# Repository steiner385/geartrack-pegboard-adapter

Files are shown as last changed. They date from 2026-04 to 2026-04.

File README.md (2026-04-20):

# GearTrack Pegboard Adapter

A 3D-printable adapter that slides into Gladiator GearTrack/GearWall channels and presents standard 1/4" pegboard holes — so you can reuse your existing pegboard hooks on GearTrack.

## Features

- **Exact GearTrack fit** — bracket profile traced from [CosmicProphet's GearTrack Mounting Brackets](https://www.thingiverse.com/thing:4075984)
- **Self-contained** — single OpenSCAD file, no external dependencies
- **Standard pegboard holes** — 1/4" (6.35mm) holes on 1" (25.4mm) centers
- **Fully parametric** — customize width, height, standoff depth, and more via OpenSCAD or Thingiverse Customizer
- **Hook clearance** — adjustable standoff (default 17mm) behind the plate for hook backs
- **Smart tab distribution** — GearTrack tabs at the edges, evenly distributed, never behind holes

## Pre-generated STLs

| File | Width × Height | Tabs | Description |
|---|---|---|---|
| `Test_Clip` | — | 1 | Print first to verify GearTrack fit |
| `2x2` | 2 × 2 | 1 | Single hook spot |
| `4x3` | 4 × 3 | 1 | Compact tool cluster |
| `4x4` | 4 × 4 | 1 | Square panel |
| `4x6` | 4 × 6 | 1 | Tall narrow panel |
| `4x8` | 4 × 8 | 1 | Very tall panel |
| `6x3` | 6 × 3 | 2 | Wide short panel |
| `6x4` | 6 × 4 | 2 | Wide standard panel |
| `8x3` | 8 × 3 | 2 | Near max bed width (220mm) |
| `8x4` | 8 × 4 | 2 | Largest single print |

## Customizer Parameters

- **Width**: Columns across (even: 2, 4, 6, 8)
- **Height**: Rows tall (1–12)
- **Standoff**: Hook clearance behind plate (12–25mm, default 17)
- **Plate thickness**: 3–8mm (default 5)
- **Hole diameter**: Default 6.35mm (1/4")
- **Hole spacing**: Default 25.4mm (1")
- **Test clip mode**: Print just the GearTrack tab to verify fit

## Print Settings

- **Orientation**: Flat on bed
- **Infill**: 50–80%, rectilinear
- **Perimeters**: 3+
- **Material**: PLA or PETG (PETG recommended for garage use)
- **Supports**: Not required

## Usage

1. Print the **Test Clip** first to verify it slides into your GearTrack
2. If too tight, increase tolerance by scaling the clip 99% in your slicer
3. Choose or customize a pegboard size
4. Print, slide into GearTrack from the end, and hang your hooks

## Files

- `geartrack_pegboard_adapter.scad` — Parametric OpenSCAD source (Thingiverse Customizer compatible)
- `GearTrack_Pegboard_*.stl` — Pre-generated common sizes

## Attribution

GearTrack bracket profile traced from [CosmicProphet's GearTrack Mounting Brackets](https://www.thingiverse.com/thing:4075984), licensed under [CC BY 4.0](https://creativecommons.org/licenses/by/4.0/).

## License

This work is licensed under [CC BY 4.0](https://creativecommons.org/licenses/by/4.0/).

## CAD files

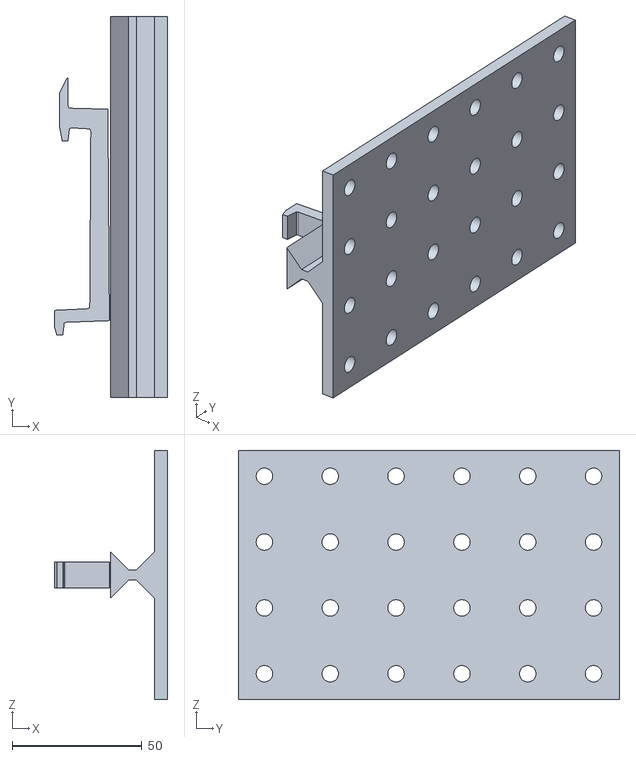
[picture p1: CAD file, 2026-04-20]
GearTrack_Pegboard_4x6.stl
43.6 x 147.0 x 96.2

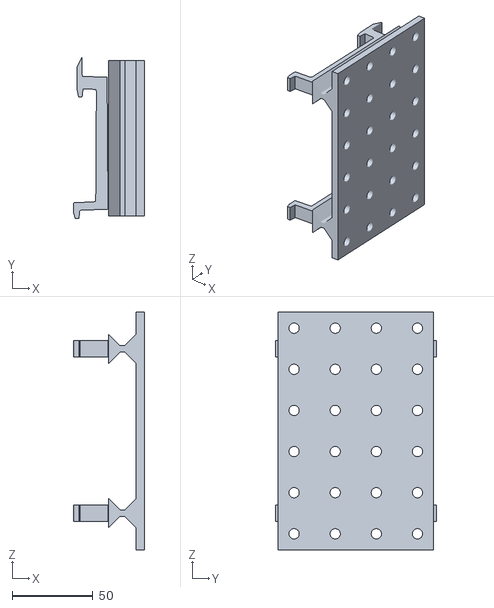
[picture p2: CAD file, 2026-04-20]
GearTrack_Pegboard_6x4.stl
43.6 x 99.2 x 147.0

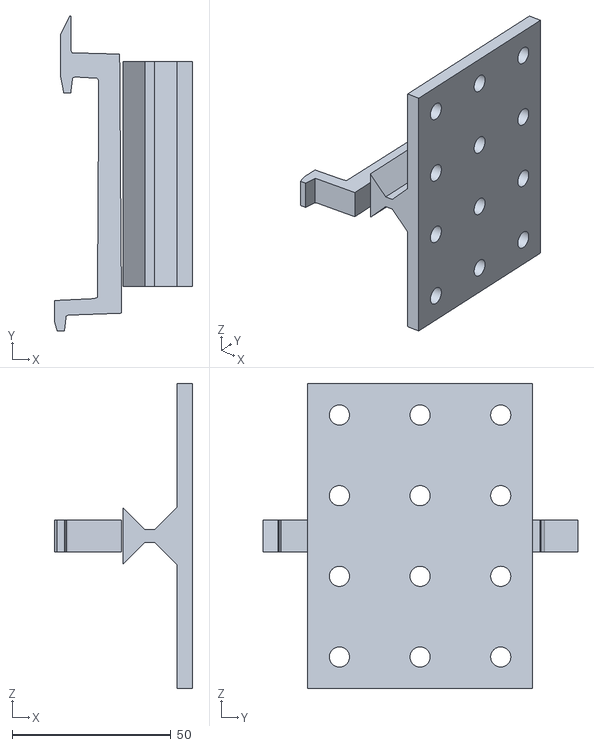
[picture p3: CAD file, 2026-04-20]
GearTrack_Pegboard_4x3.stl
43.6 x 99.2 x 96.2

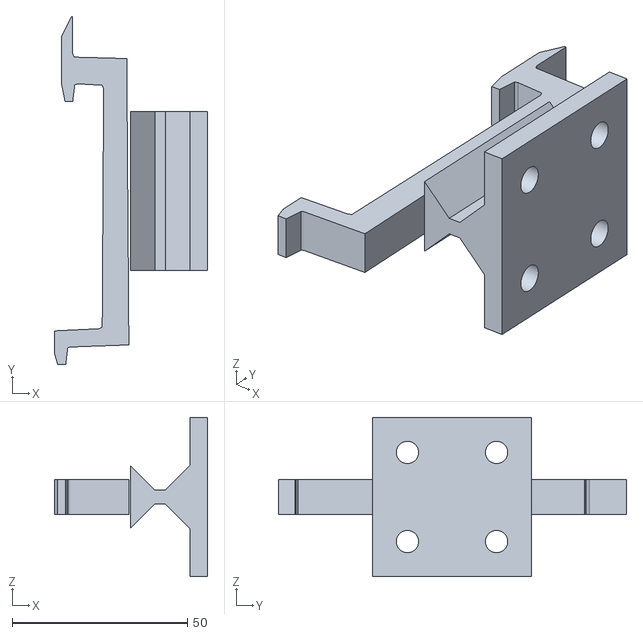
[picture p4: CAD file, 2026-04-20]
GearTrack_Pegboard_2x2.stl
43.6 x 99.2 x 45.4

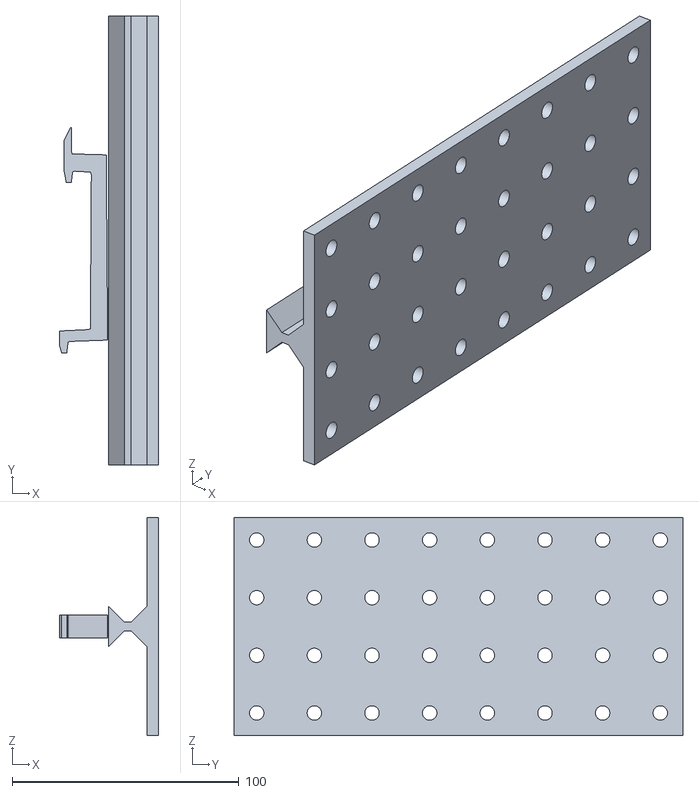
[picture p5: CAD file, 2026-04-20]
GearTrack_Pegboard_4x8.stl
43.6 x 197.8 x 96.2

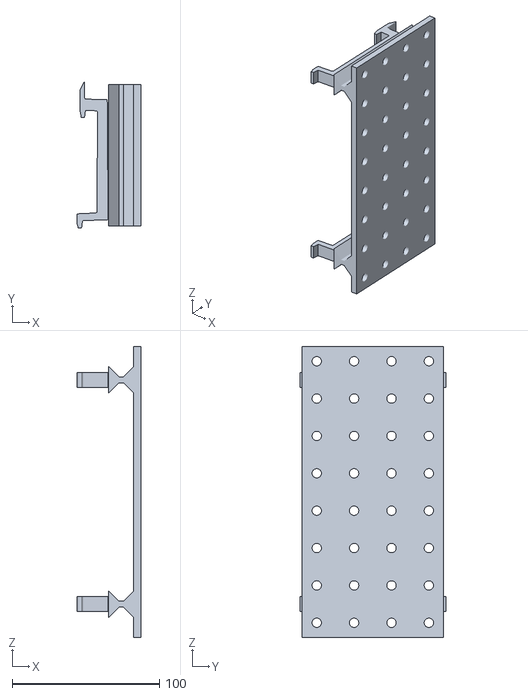
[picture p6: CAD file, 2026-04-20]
GearTrack_Pegboard_8x4.stl
43.6 x 99.2 x 197.8

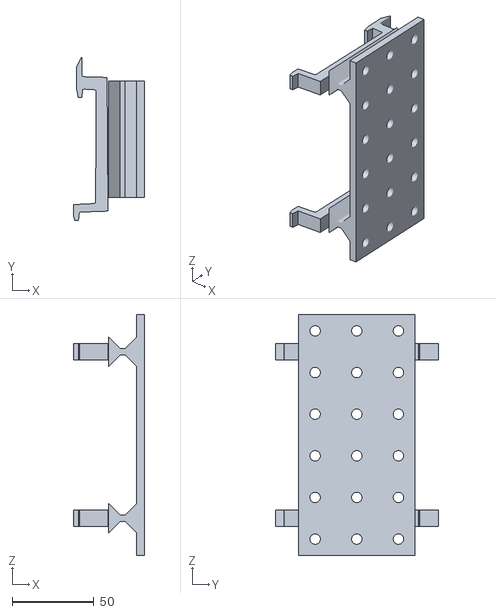
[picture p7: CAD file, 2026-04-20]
GearTrack_Pegboard_6x3.stl
43.6 x 99.2 x 147.0

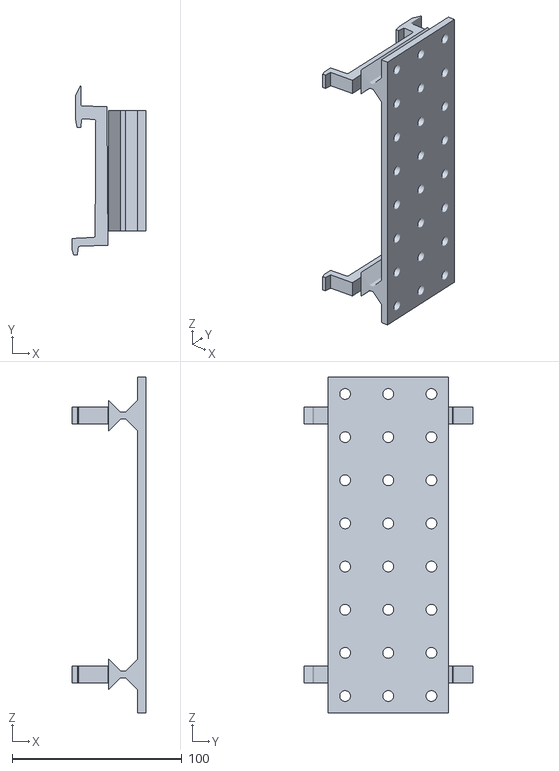
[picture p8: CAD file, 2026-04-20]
GearTrack_Pegboard_8x3.stl
43.6 x 99.2 x 197.8

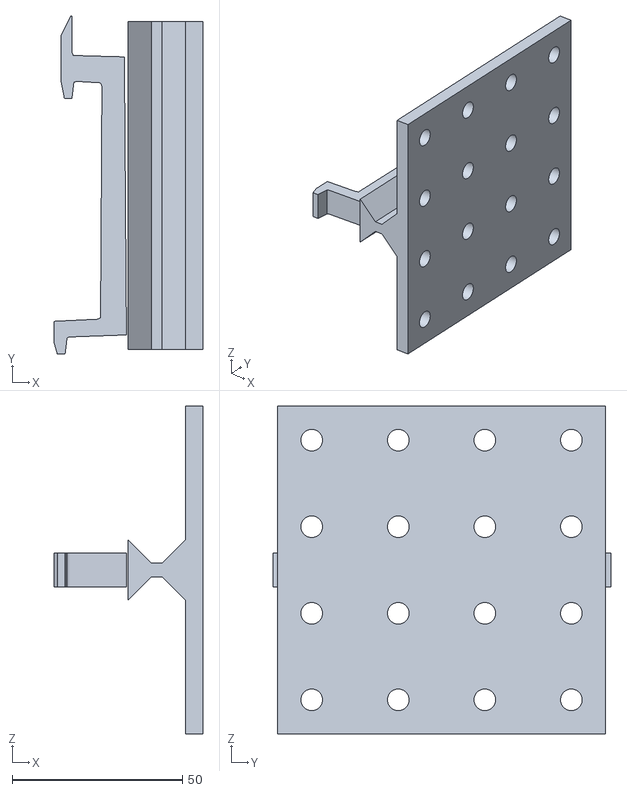
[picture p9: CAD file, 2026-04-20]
GearTrack_Pegboard_4x4.stl
43.6 x 99.2 x 96.2

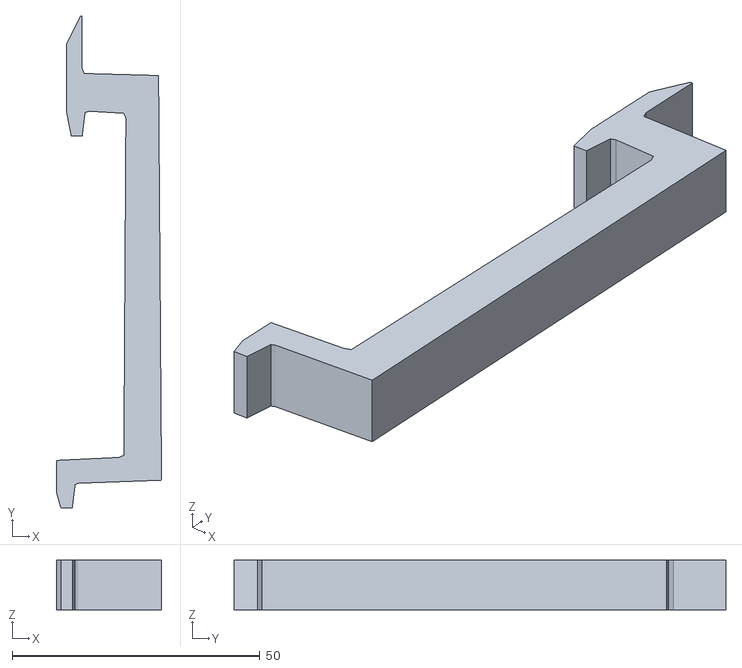
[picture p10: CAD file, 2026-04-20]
GearTrack_Pegboard_Test_Clip.stl
21.2 x 99.2 x 10.0

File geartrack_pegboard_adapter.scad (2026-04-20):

// GearTrack-to-Pegboard Adapter
// Slides into Gladiator GearTrack/GearWall channels and presents
// standard 1/4" pegboard holes for your existing hooks.
//
// Self-contained — no external dependencies.
// Bracket profile derived from CosmicProphet's GearTrack Mounting
// Brackets (Thingiverse thing:4075984), licensed CC BY 4.0.
//
// Print settings:
//   Orientation: flat on bed
//   Infill: 50-80%, rectilinear
//   Perimeters: 3+
//   Material: PLA or PETG (PETG recommended for garage use)
//   Supports: not required

/* [Pegboard] */

// Columns across (horizontal, along the track). Even numbers only.
width = 4; // [2, 4, 6, 8]

// Rows tall (vertical, up the wall)
height = 3; // [1:1:12]

// Hole diameter in mm (standard = 6.35 / 1/4 inch)
hole_dia = 6.35;

// Hole center-to-center spacing in mm (standard = 25.4 / 1 inch)
hole_spacing = 25.4;

/* [Plate] */

// Plate thickness in mm
plate_thick = 5.0; // [3:0.5:8]

// Margin around outermost holes in mm
plate_margin = 10.0; // [5:1:15]

/* [Standoff] */

// Space behind plate for hook backs (mm). Standard hooks need 15-20mm.
standoff = 17.0; // [12:1:25]

// Rib thickness in mm (horizontal direction)
rib_thick = 4.0; // [3:0.5:6]

// Gusset size in mm (triangular reinforcement at rib joints)
// Max safe value = hole_spacing/2 - rib_thick/2 - hole_dia/2
gusset = 7.0; // [4:0.5:9]

/* [Advanced] */

// Tab width in mm (along the track)
tab_width = 10; // [8:1:14]

// Print just one bracket tab to test GearTrack fit
test_clip = false;

/* [Hidden] */

$fn = 40;

// ----- BRACKET PROFILE -----
// Exact 2D boundary polygon extracted from the Z=0 face of
// CosmicProphet's Gearwall_Bracket_10mm.stl
// (Thingiverse thing:4075984, CC BY 4.0)
// X = depth (negative=wall, positive=room), Y = height
_bracket_profile = [
    [  -6.000,  -62.467],
    [  10.600,  -61.867],
    [  10.000,   19.733],
    [  -4.990,   20.143],
    [  -5.400,   21.133],
    [  -5.400,   31.733],
    [  -5.753,   31.733],
    [  -8.600,   26.039],
    [  -8.600,   12.592],
    [  -7.620,    7.533],
    [  -5.400,    7.533],
    [  -4.823,   12.266],
    [  -4.000,   12.533],
    [   2.990,   12.123],
    [   3.400,   11.133],
    [   2.990,  -56.857],
    [   2.000,  -57.267],
    [ -10.600,  -57.867],
    [ -10.600,  -64.344],
    [  -9.699,  -67.467],
    [  -7.400,  -67.467],
    [  -6.823,  -62.734],
    [  -6.219,  -62.484]
];

module bracket_tab() {
    linear_extrude(height = tab_width)
        polygon(points = _bracket_profile);
}

// ----- DERIVED -----
plate_w = (width - 1) * hole_spacing + 2 * plate_margin;
plate_h = (height - 1) * hole_spacing + 2 * plate_margin;

num_tabs = max(1, ceil(width / 4));

bracket_height = 100;
bracket_y_min  = -68;
bracket_front  = 11;

num_gaps = width - 1;

function tab_gap_index(i, n, gaps) =
    (n == 1) ? floor(gaps / 2) :
    floor(i * (gaps - 1) / (n - 1));

function gap_z(gap_idx) =
    plate_margin + (gap_idx + 0.5) * hole_spacing;

// ----- MODULES -----

module pegboard_plate() {
    difference() {
        cube([plate_thick, plate_h, plate_w]);
        for (col = [0 : width - 1]) {
            for (row = [0 : height - 1]) {
                translate([-1, plate_margin + row * hole_spacing, plate_margin + col * hole_spacing])
                    rotate([0, 90, 0])
                        cylinder(h = plate_thick + 2, d = hole_dia);
            }
        }
    }
}

module rib() {
    cube([standoff, plate_h, rib_thick]);
}

module gusset_wedge(leg_x, leg_z, h) {
    polyhedron(
        points = [
            [0, 0, 0], [leg_x, 0, 0], [0, 0, leg_z],
            [0, h, 0], [leg_x, h, 0], [0, h, leg_z]
        ],
        faces = [
            [0, 2, 1], [3, 4, 5],
            [0, 1, 4, 3], [1, 2, 5, 4], [0, 3, 5, 2]
        ]
    );
}

// ----- ASSEMBLY -----

if (test_clip) {
    bracket_tab();
} else {
    plate_y_offset = bracket_y_min + (bracket_height - plate_h) / 2;

    for (i = [0 : num_tabs - 1]) {
        gi = tab_gap_index(i, num_tabs, num_gaps);
        rz = gap_z(gi);
        g = gusset;

        // Bracket tab
        translate([0, 0, rz - tab_width / 2])
            bracket_tab();

        // Vertical rib
        translate([bracket_front, plate_y_offset, rz - rib_thick / 2])
            rib();

        // Gussets (4 wedges per rib)
        translate([bracket_front, plate_y_offset, rz - rib_thick / 2])
            gusset_wedge(g, -g, plate_h);
        translate([bracket_front, plate_y_offset, rz + rib_thick / 2])
            gusset_wedge(g, g, plate_h);
        translate([bracket_front + standoff, plate_y_offset, rz - rib_thick / 2])
            gusset_wedge(-g, -g, plate_h);
        translate([bracket_front + standoff, plate_y_offset, rz + rib_thick / 2])
            gusset_wedge(-g, g, plate_h);
    }

    // Pegboard plate
    translate([bracket_front + standoff, plate_y_offset, 0])
        pegboard_plate();
}

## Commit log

2026-04-20 Initial release: GearTrack-to-Pegboard adapter
    Parametric OpenSCAD adapter that slides into Gladiator GearTrack/GearWall
    channels and presents standard 1/4" pegboard holes for existing hooks.
    - Exact bracket profile from CosmicProphet (thing:4075984)
    - Customizable width, height, standoff, plate thickness
    - Smart edge-to-edge tab distribution (1 per 4 columns)
    - Pre-generated STLs for 9 common sizes + test clip
    [GearTrack_Pegboard_2x2.stl, GearTrack_Pegboard_4x3.stl, GearTrack_Pegboard_4x4.stl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]
2026-04-20 Remove STL dependency — embed bracket profile as polygon
    - Traced bracket cross-section into 27-point OpenSCAD polygon
    - Removed Gearwall_Bracket_10mm.stl dependency
    - Single self-contained .scad file, no external files needed
    - Regenerated all pre-built STLs from polygon profile
    - Updated README
    [GearTrack_Pegboard_2x2.stl, GearTrack_Pegboard_4x3.stl, GearTrack_Pegboard_4x4.stl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]
2026-04-20 Add gusset reinforcements at rib joints
    Triangular wedges at each rib-to-bracket and rib-to-plate connection
    spread the load across the Z axis, preventing snap-off at the joints.
    Configurable gusset size (default 10mm, range 6-15mm).
    [GearTrack_Pegboard_2x2.stl, GearTrack_Pegboard_4x3.stl, GearTrack_Pegboard_4x4.stl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]
2026-04-20 Fix bracket profile: replace broken polygon with CSG rectangles
    The polygon trace had self-intersections due to the C-clip geometry
    (outline crosses itself where arms wrap around the rail). Replaced
    with union of 22 rectangles that faithfully recreate the profile.
    Still fully self-contained — no external STL dependency.
    [GearTrack_Pegboard_2x2.stl, GearTrack_Pegboard_4x3.stl, GearTrack_Pegboard_4x4.stl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]
2026-04-20 Fix bracket tabs: solid structural sections instead of thin slices
    Previous decomposition created 0.5mm-tall strips at each Y level.
    Now uses 15 solid rectangular sections that form proper C-clips:
    - Lower hook: tab tip, back post, under-rail arm, front post, over-rail arm
    - Bridge: solid plate connecting lower to upper (64mm)
    - Upper hook: same structure mirrored
    [GearTrack_Pegboard_2x2.stl, GearTrack_Pegboard_4x3.stl, GearTrack_Pegboard_4x4.stl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]
2026-04-20 Rebuild bracket as overlapping solid rectangles
    Each C-clip is now built from overlapping rectangular sections
    (1-2mm overlap) that fuse into a single connected solid:
    - Lower clip: back plate, bottom arm, front post, top arm
    - Bridge: single solid plate connecting clips
    - Upper clip: same structure
    All variants now render as Simple=yes (valid manifold geometry).
    Fixes disconnected fragments visible in Cura.
    [GearTrack_Pegboard_2x2.stl, GearTrack_Pegboard_4x3.stl, GearTrack_Pegboard_4x4.stl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]
2026-04-20 Extract exact boundary polygon from STL face
    Traced the actual perimeter of the Z=0 face by chaining boundary
    edges (edges belonging to only one triangle). Produces a clean
    23-vertex non-self-intersecting polygon that exactly matches the
    original bracket cross-section.
    Previous approaches failed because:
    - min/max X trace: self-intersecting at C-clip transitions
    - Rectangle decomposition: blocky, disconnected fragments
    [GearTrack_Pegboard_2x2.stl, GearTrack_Pegboard_4x3.stl, GearTrack_Pegboard_4x4.stl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]
2026-04-20 Reduce gusset from 10mm to 7mm — was overlapping pegboard holes
    Gussets at 10mm extended past the nearest hole edge (9.5mm from rib
    center). Reduced to 7mm with 2.5mm clearance to holes. Updated
    slider range to 4-9mm.
    [GearTrack_Pegboard_2x2.stl, GearTrack_Pegboard_4x3.stl, GearTrack_Pegboard_4x4.stl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]
